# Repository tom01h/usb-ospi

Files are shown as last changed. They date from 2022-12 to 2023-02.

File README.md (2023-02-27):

# PCとFPGAをUSB接続する

## 概要
以下の接続でPCとFPGA間の高速転送をしたいプロジェクト。  
今はRead120Mbps,Write100Mbpsくらい。  
LinuxPC ←(USB-HS)→ USB3300 ←(ULPI)→ STM32H7B0 ←(OCTO SPI)→ FPGA

FPGA内ではAXIマスターポートをつける予定だけど、まだSPIクロックで動くBRAMにアクセスできるだけ。

USB転送はPCでは[libusb](https://github.com/libusb/libusb)、STM32では[tinyusb](https://github.com/hathach/tinyusb)を使ってVendorSpecificなバルク転送をします。  
OCTO SPIはSTM32はHALを使って、FPGAは適当に作ったRTLを使います。

## 部品
- PCはLinuxPCならたぶん何でもよい
- 基板を1枚こしらえました（[スケマ](https://github.com/tom01h/usb-ospi/blob/master/PCB/QMTECH/ospi.pdf)）
    - この基板の動作確認は200Tのみ
    - [8ピンのデータ用type-Cコネクタ](https://ja.aliexpress.com/item/1005004277420642.html)
    - [6ピンの電源用type-Cコネクタ](https://ja.aliexpress.com/item/1005004384274891.html)
    - USB3300-EZK
    - 24MHz 3225 のパッシブクォーツ水晶発振器 (2と4がグランド)
    - 1206 の抵抗とかコンデンサ
    - コネクタは次の組み合わせでぎりぎり干渉しない
        - STM32をとめる[コネクタ](https://ja.aliexpress.com/item/32892386779.html)
        - FPGAをとめる[コネクタオス](https://ja.aliexpress.com/item/1005004843759392.html)
            - これの11.2を、ピンが基板からはみ出ないところまでプラスチックをずらして使用
            - メスは普通のやつ
    - 他…
- QMTECHのFPGA (どっちか1個)
    - [200T](https://ja.aliexpress.com/item/1005002960622091.html)
    - [100T](https://ja.aliexpress.com/item/4000170003461.html)
- STM32H7
    - [WeActStudioのボード](https://ja.aliexpress.com/item/1005004466900940.html)
## 使い方
### ホスト
```
cd host/
cmake .
make
sudo ./main
```
### ファームウェア
- `firm/tinyusb`の下にtinyusbをクローンする
    - このリポジトリにあるファイルで上書きする
- usb_octospi.iocからプロジェクトを作る
    - このリポジトリにあるファイルで上書きする
- [ここ](https://github.com/hathach/tinyusb/discussions/633)に従って参照パスを追加する
```
- Right click the project, go to properties. in C/C++ General -> Paths and Symbols, in the "Includes" tab add a path, make it a workspace path, point it to the tinyusb/src directory. Then, in the "Source Location" tab, add folder, and also point it to tinyusb/src
- Add a tusb_config.h to your "Core/Inc"
```
### FPGA
- [なひビバ](https://github.com/tokuden/NahiViva)で次のどちらかのプロジェクトを再生してビルドする
    - QMT100/
    - QMT200/

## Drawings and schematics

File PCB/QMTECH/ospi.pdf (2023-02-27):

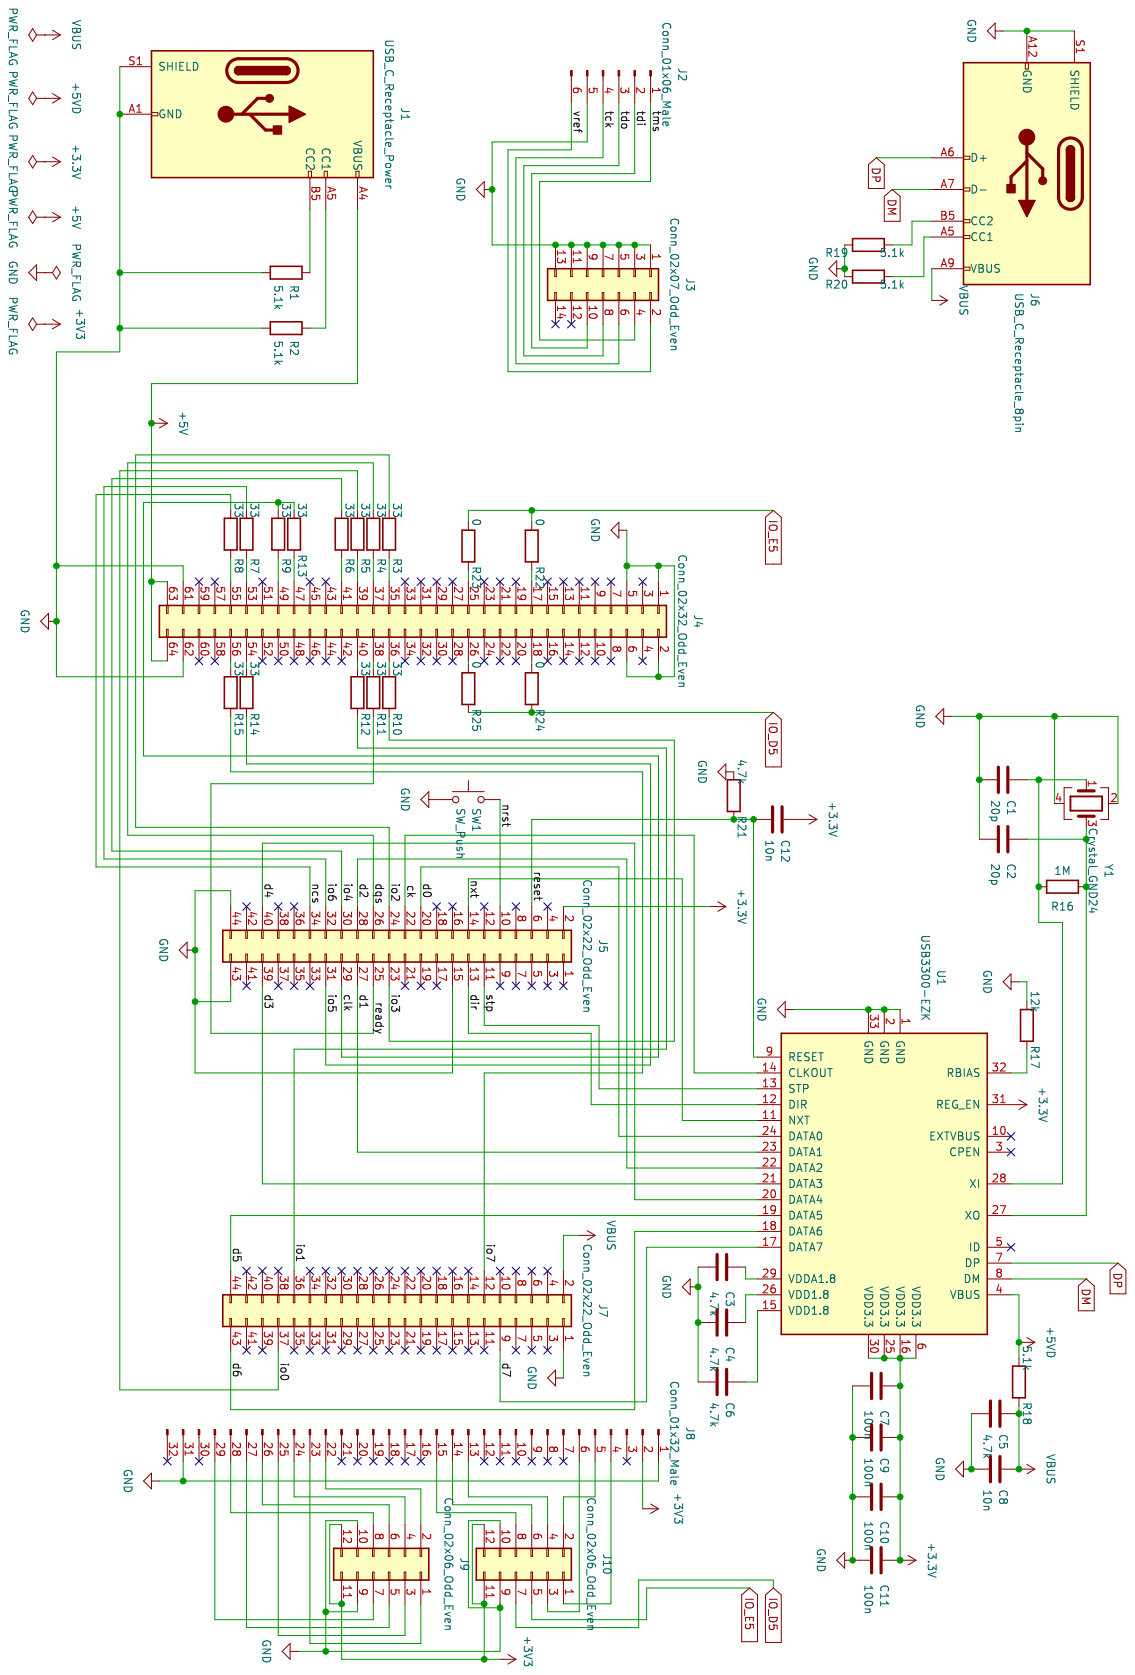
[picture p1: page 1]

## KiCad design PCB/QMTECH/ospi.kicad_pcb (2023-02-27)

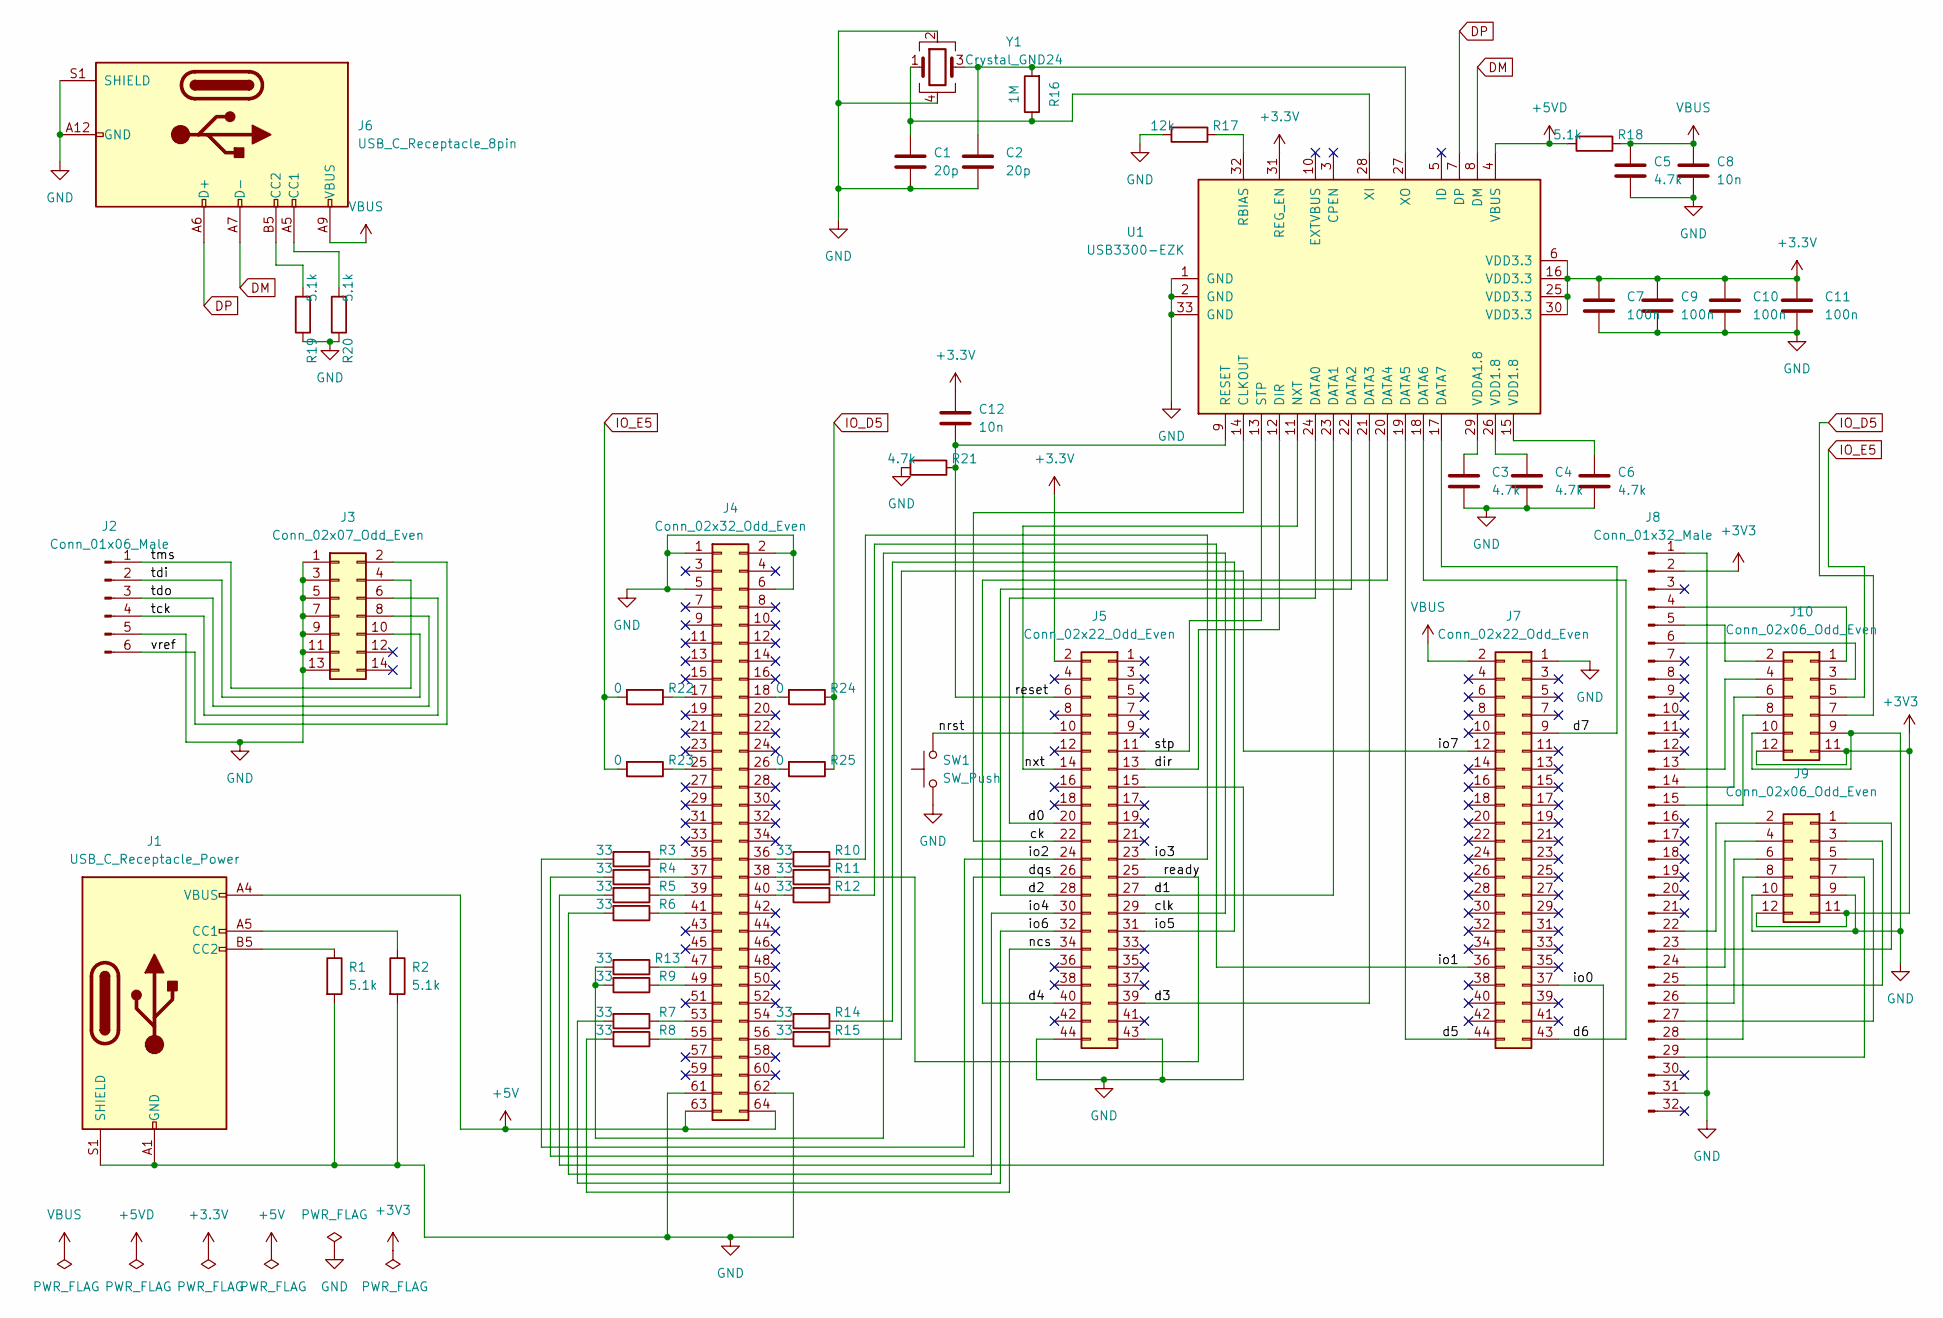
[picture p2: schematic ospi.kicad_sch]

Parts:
C1, C2: 20p; C_1206_3216Metric_Pad1.33x1.80mm_HandSolder
C3, C4, C5, C6: 4.7k; C_1206_3216Metric_Pad1.33x1.80mm_HandSolder
C7, C9, C10, C11: 100n; C_1206_3216Metric_Pad1.33x1.80mm_HandSolder
C8, C12: 10n; C_1206_3216Metric_Pad1.33x1.80mm_HandSolder
J1: USB_C_Receptacle_Power
J2: Conn_01x06_Male; PinSocket_1x06_P2.54mm_Vertical
J3: Conn_02x07_Odd_Even; PinHeader_2x07_P2.00mm_Vertical
J4: Conn_02x32_Odd_Even; PinSocket_2x32_P2.54mm_Vertical
J5, J7: Conn_02x22_Odd_Even; PinSocket_2x22_P2.54mm_Vertical
J6: USB_C_Receptacle_8pin
J8: Conn_01x32_Male; PinSocket_1x32_P2.54mm_Vertical
J9, J10: Conn_02x06_Odd_Even; PinSocket_2x06_P2.54mm_Vertical
R1, R2, R18, R19, R20: 5.1k; R_1206_3216Metric_Pad1.30x1.75mm_HandSolder
R3, R4, R5, R6, R7, R8, R9, R10, R11, R12, R13, R14, R15: 33; R_1206_3216Metric_Pad1.30x1.75mm_HandSolder
R16: 1M; R_1206_3216Metric_Pad1.30x1.75mm_HandSolder
R17: 12k; R_1206_3216Metric_Pad1.30x1.75mm_HandSolder
R21: 4.7k; R_1206_3216Metric_Pad1.30x1.75mm_HandSolder
R22, R23, R24, R25: 0; R_1206_3216Metric_Pad1.30x1.75mm_HandSolder
SW1: SW_Push; SW_SPST_CK_RS282G05A3
U1: USB3300-EZK; QFN-32-1EP_5x5mm_P0.5mm_EP3.45x3.45mm_ThermalVias
Y1: Crystal_GND24; Crystal_SMD_3225-4Pin_3.2x2.5mm_HandSoldering

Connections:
+3.3V: C7.1, C9.1, C10.1, C11.1, C12.1, J5.2, U1.6 (VDD3.3), U1.16 (VDD3.3), U1.25 (VDD3.3), U1.30 (VDD3.3), U1.31 (REG_EN)
+3V3: J8.2, J9.11, J9.12, J10.11, J10.12
+5V: J1.A4 (VBUS), J1.A9 (VBUS), J1.B4 (VBUS), J1.B9 (VBUS), J4.63, J4.64
+5VD: R18.2, U1.4 (VBUS)
/ck: J5.22, U1.14 (CLKOUT)
/clk: J5.29, R9.2, R13.2
/d0: J5.20, U1.24 (DATA0)
/d1: J5.27, U1.23 (DATA1)
/d2: J5.28, U1.22 (DATA2)
/d3: J5.39, U1.21 (DATA3)
/d4: J5.40, U1.20 (DATA4)
/d5: J7.44, U1.19 (DATA5)
/d6: J7.43, U1.18 (DATA6)
/d7: J7.9, U1.17 (DATA7)
/dir: J5.13, U1.12 (DIR)
/dqs: J5.26, R4.2
/io0: J7.37, R5.2
/io1: J7.36, R12.1
/io2: J5.24, R3.2
/io3: J5.23, R10.1
/io4: J5.30, R6.2
/io5: J5.31, R14.1
/io6: J5.32, R7.2
/io7: J7.12, R15.1
/ncs: J5.34, R8.2
/nrst: J5.10, SW1.2
/nxt: J5.14, U1.11 (NXT)
/ready: J5.25, R11.1
/reset: C12.2, J5.6, R21.1, U1.9 (RESET)
/stp: J5.11, U1.13 (STP)
/tck: J2.4, J3.6
/tdi: J2.2, J3.10
/tdo: J2.3, J3.8
/tms: J2.1, J3.4
/vref: J2.6, J3.2
DM: J6.A7 (D-), U1.8 (DM)
DP: J6.A6 (D+), U1.7 (DP)
GND: C1.2, C2.2, C3.2, C4.2, C5.2, C6.2, C7.2, C8.2, C9.2, C10.2, C11.2, J1.A1 (GND), J1.A12 (GND), J1.B1 (GND), J1.B12 (GND), J1.S1 (SHIELD), J2.5, J3.1, J3.3, J3.5, J3.7, J3.9, J3.11, J3.13, J4.1, J4.2, J4.5, J4.6, J4.61, J4.62, J5.15, J5.43, J5.44, J6.A12 (GND), J6.B12 (GND), J6.S1 (SHIELD), J7.1, J8.1, J8.31, J9.9, J9.10, J10.9, J10.10, R1.2, R2.2, R17.2, R19.1, R20.1, R21.2, SW1.1, U1.1 (GND), U1.2 (GND), U1.33 (GND), Y1.2, Y1.4
IO_D5: J10.7, R24.1, R25.1
IO_E5: J10.5, R22.2, R23.2
unnamed: C1.1, R16.1, U1.28 (XI), Y1.1
unnamed: C2.1, R16.2, U1.27 (XO), Y1.3
unnamed: C3.1, U1.29 (VDDA1.8)
unnamed: C4.1, U1.26 (VDD1.8)
unnamed: C6.1, U1.15 (VDD1.8)
unnamed: J1.A5 (CC1), R2.1
unnamed: J1.B5 (CC2), R1.1
unnamed: J4.17, R22.1
unnamed: J4.18, R24.2
unnamed: J4.25, R23.1
unnamed: J4.26, R25.2
unnamed: J4.35, R3.1
unnamed: J4.36, R10.2
unnamed: J4.37, R4.1
unnamed: J4.38, R11.2
unnamed: J4.39, R5.1
unnamed: J4.40, R12.2
unnamed: J4.41, R6.1
unnamed: J4.47, R13.1
unnamed: J4.49, R9.1
unnamed: J4.53, R7.1
unnamed: J4.54, R14.2
unnamed: J4.55, R8.1
unnamed: J4.56, R15.2
unnamed: J6.A5 (CC1), R20.2
unnamed: J6.B5 (CC2), R19.2
unnamed: J8.22, J9.2
unnamed: J8.23, J9.1
unnamed: J8.24, J9.4
unnamed: J8.25, J9.3
unnamed: J8.26, J9.6
unnamed: J8.27, J9.5
unnamed: J8.28, J9.8
unnamed: J8.29, J9.7
unnamed: J8.4, J10.1
unnamed: J8.5, J10.2
unnamed: J8.6, J10.3
unnamed: J8.13, J10.4
unnamed: J8.14, J10.6
unnamed: J8.15, J10.8
unnamed: R17.1, U1.32 (RBIAS)
VBUS: C5.1, C8.1, J6.A9 (VBUS), J6.B9 (VBUS), J7.2, R18.1

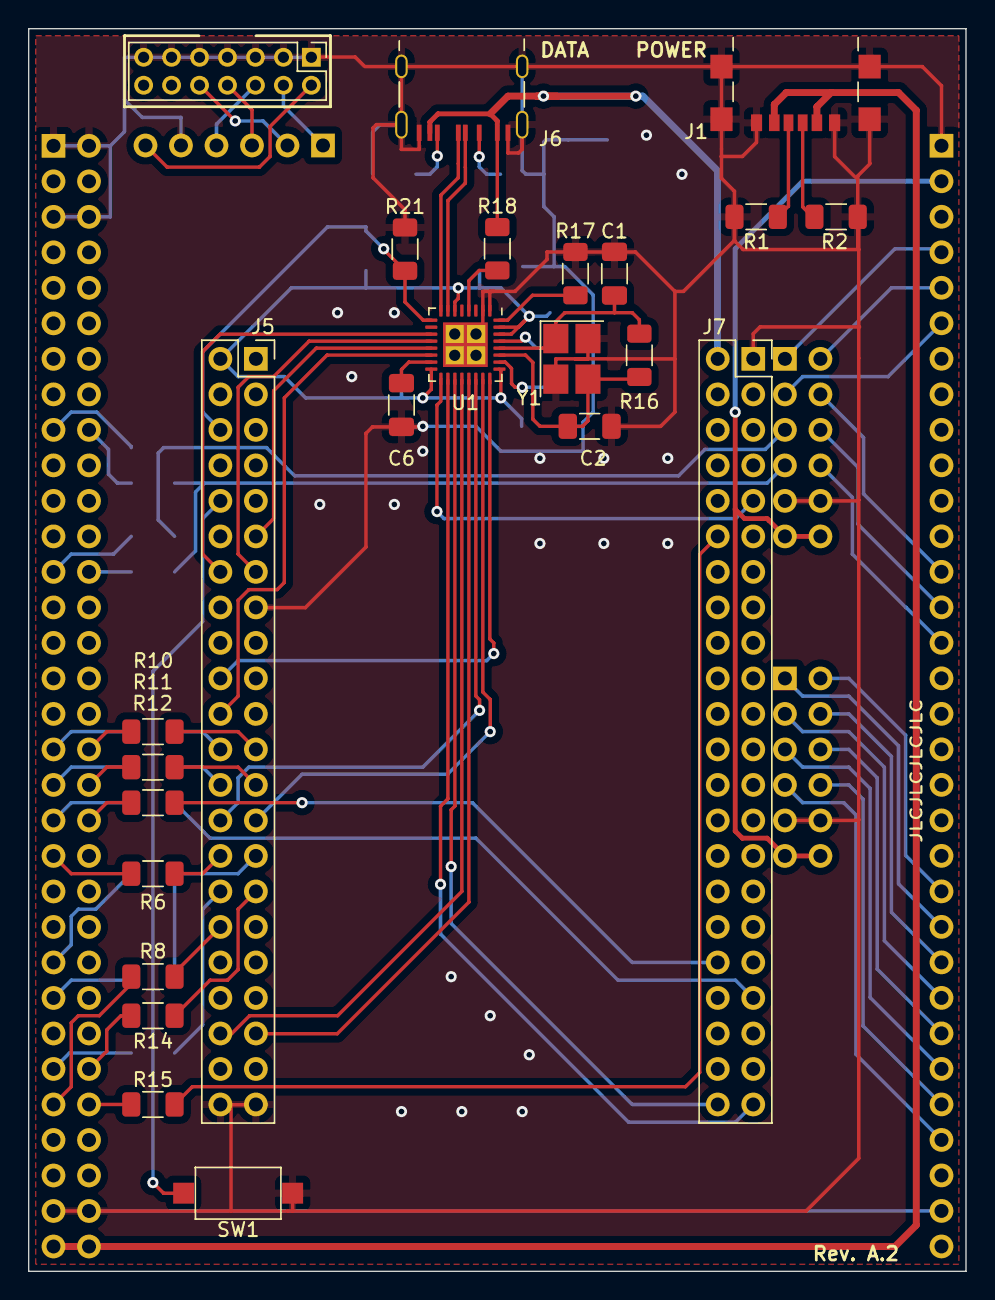
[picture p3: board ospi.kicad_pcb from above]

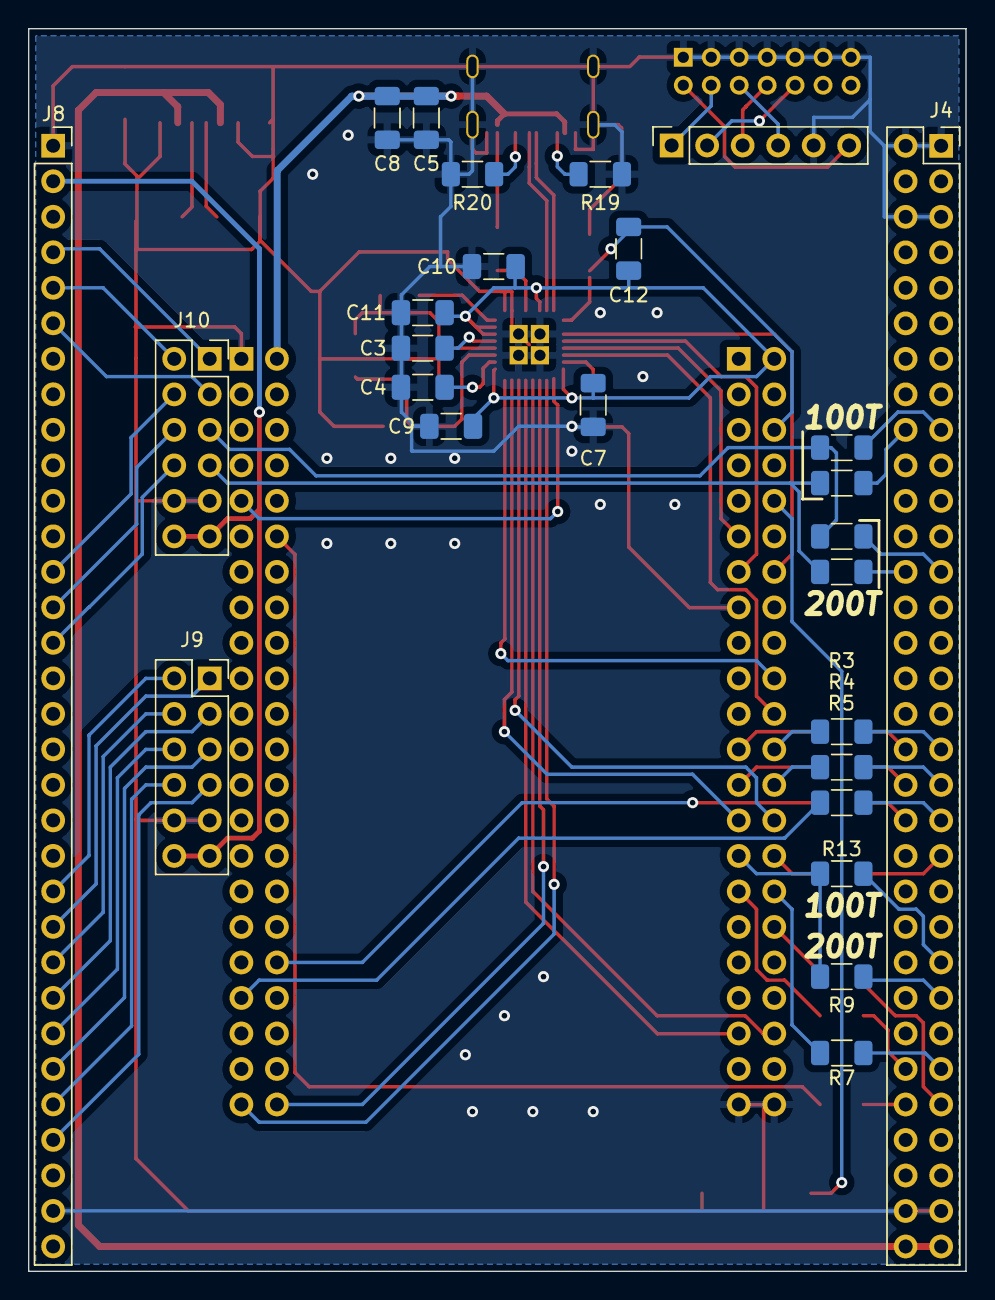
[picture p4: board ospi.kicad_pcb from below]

Board: 2 copper layers, 67.1 x 88.9 mm, 50 parts (26 on the bottom side), 82 nets.

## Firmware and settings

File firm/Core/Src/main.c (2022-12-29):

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
/* Includes ------------------------------------------------------------------*/
#include "main.h"

/* USER CODE BEGIN Includes */
#include "tusb.h"

/* USER CODE END Includes */


OSPI_HandleTypeDef hospi1;
MDMA_HandleTypeDef hmdma_octospi1_fifo_th;

PCD_HandleTypeDef hpcd_USB_OTG_HS;

/* USER CODE BEGIN PV */
buffer_info buffer_info_axm;

/* USER CODE END PV */

void SystemClock_Config(void);
static void MX_GPIO_Init(void);
static void MX_MDMA_Init(void);
static void MX_OCTOSPI1_Init(void);
static void MX_USB_OTG_HS_PCD_Init(void);
/* USER CODE BEGIN 0 */

void from_host_task(OSPI_RegularCmdTypeDef *sCommand)
{
	if ((buffer_info_axm.busy == false)) {
		buffer_info_axm.busy = true;
		uint com_size = 0;
		if (tud_vendor_available()) {
			com_size = tud_vendor_read(buffer_info_axm.buffer[0], 512);
			//tud_vendor_read_flush();
		}else{
			tud_task();
		}
		if (com_size != 0) {
			sCommand->Instruction = *(uint32_t *)&buffer_info_axm.buffer[0][0];
			buffer_info_axm.count = (sCommand->Instruction & 0x00ffffff)+1;

			sCommand->Address     = *(uint32_t *)&buffer_info_axm.buffer[0][4];

			uint count = buffer_info_axm.count;

			if((buffer_info_axm.buffer[0][3]&0xf0)==(LINEAR_BURST_WRITE<<4)) {     // LINEAR_BURST_WRITE
				sCommand->DummyCycles = DUMMY_CLOCK_CYCLES_SRAM_WRITE;
				int wp = 0;
				int rp = 0;
				while(tud_vendor_read(buffer_info_axm.buffer[wp], 512) == 0){tud_task();}
				do{
					if(count > 256){
						sCommand->NbData  = 256;
						count -= 256;
						sCommand->Instruction &= 0xff0000ff;/////////////|0xff
					} else {
						sCommand->NbData  = count;
						count = 0;
						sCommand->Instruction &= 0xff0000ff;
					}
					SCB_CleanDCache_by_Addr((uint32_t*)buffer_info_axm.buffer[rp], 512);

					if (HAL_OSPI_Command(&hospi1, sCommand, HAL_OSPI_TIMEOUT_DEFAULT_VALUE) != HAL_OK) {Error_Handler();}
					if (HAL_OSPI_Transmit_DMA(&hospi1, buffer_info_axm.buffer[rp])!= HAL_OK)           {Error_Handler();}
					while(HAL_OSPI_GetState(&hospi1) == HAL_OSPI_STATE_BUSY_TX){}
					sCommand->Address += 256;

					if(count > 0){
						if(count > 256){
							sCommand->NbData  = 256;
							count -= 256;
							sCommand->Instruction &= 0xff0000ff;/////////////|0xff
						} else {
							sCommand->NbData  = count;
							count = 0;
							sCommand->Instruction &= 0xff0000ff;
						}

						if (HAL_OSPI_Command(&hospi1, sCommand, HAL_OSPI_TIMEOUT_DEFAULT_VALUE) != HAL_OK) {Error_Handler();}
						if (HAL_OSPI_Transmit_DMA(&hospi1, &buffer_info_axm.buffer[rp][256])!= HAL_OK)     {Error_Handler();}
						if(count > 0) {
							wp = (wp +1) %2;
							while(tud_vendor_read(buffer_info_axm.buffer[wp], 512) == 0){tud_task();}
						}
						while(HAL_OSPI_GetState(&hospi1) == HAL_OSPI_STATE_BUSY_TX){}
						sCommand->Address += 256;
					}
					rp = (rp +1) %2;
				} while(count > 0);
			} else {                                                             // LINEAR_BURST_READ
				sCommand->DummyCycles = DUMMY_CLOCK_CYCLES_SRAM_READ;
				int wp = 0;
				int rp = 0;
				do{
					SCB_InvalidateDCache_by_Addr((uint32_t*)buffer_info_axm.buffer[wp], 512);

					if(count > 256){
						sCommand->NbData  = 256;
						count -= 256;
						sCommand->Instruction &= 0xff0000ff;/////////////|0xff
					} else {
						sCommand->NbData  = count;
						count = 0;
						sCommand->Instruction &= 0xff0000ff;
					}

					if (HAL_OSPI_Command(&hospi1, sCommand, HAL_OSPI_TIMEOUT_DEFAULT_VALUE) != HAL_OK) {Error_Handler();}
					if (HAL_OSPI_Receive_DMA(&hospi1, buffer_info_axm.buffer[wp])!= HAL_OK)            {Error_Handler();}
					if(rp != wp) {
						while(tud_vendor_write(buffer_info_axm.buffer[rp], 512) == 0){tud_task();}///////////////////////////////512
						rp = (rp +1) %2;
					}
					while(HAL_OSPI_GetState(&hospi1) == HAL_OSPI_STATE_BUSY_RX){}
					sCommand->Address += 256;

					if(count > 0){
						if(count > 256){
							sCommand->NbData  = 256;
							count -= 256;
							sCommand->Instruction &= 0xff0000ff;/////////////|0xff
						} else {
							sCommand->NbData  = count;
							count = 0;
							sCommand->Instruction &= 0xff0000ff;
						}

						if (HAL_OSPI_Command(&hospi1, sCommand, HAL_OSPI_TIMEOUT_DEFAULT_VALUE) != HAL_OK) {Error_Handler();}
						if (HAL_OSPI_Receive_DMA(&hospi1, &buffer_info_axm.buffer[wp][256])!= HAL_OK)      {Error_Handler();}
						while(HAL_OSPI_GetState(&hospi1) == HAL_OSPI_STATE_BUSY_RX){}
						sCommand->Address += 256;
					}

					wp = (wp +1) %2;
					tud_vendor_flush();
				} while(count > 0);
				while(tud_vendor_write(buffer_info_axm.buffer[rp], 512) == 0){tud_task();}///////////////////////////////512
			}
		}
		buffer_info_axm.busy = false;
	}
}

/* USER CODE END 0 */

/**
  * @brief  The application entry point.
  * @retval int
  */
int main(void)
{
  /* Enable I-Cache---------------------------------------------------------*/
  SCB_EnableICache();

  /* Enable D-Cache---------------------------------------------------------*/
  SCB_EnableDCache();

  /* MCU Configuration--------------------------------------------------------*/

  /* Reset of all peripherals, Initializes the Flash interface and the Systick. */
  HAL_Init();

  /* Configure the system clock */
  SystemClock_Config();

  /* Initialize all configured peripherals */
  MX_GPIO_Init();
  MX_MDMA_Init();
  MX_OCTOSPI1_Init();
  MX_USB_OTG_HS_PCD_Init();
  /* Infinite loop */
  /* USER CODE BEGIN WHILE */
  tusb_init();

  OSPI_RegularCmdTypeDef sCommand;
  sCommand.OperationType = HAL_OSPI_OPTYPE_COMMON_CFG;
  sCommand.FlashId = HAL_OSPI_FLASH_ID_1;
  sCommand.InstructionMode = HAL_OSPI_INSTRUCTION_8_LINES;
  sCommand.InstructionSize = HAL_OSPI_INSTRUCTION_32_BITS;
  sCommand.AddressMode = HAL_OSPI_ADDRESS_8_LINES;
  sCommand.AddressSize = HAL_OSPI_ADDRESS_32_BITS;
  sCommand.AlternateBytesMode = HAL_OSPI_ALTERNATE_BYTES_NONE;
  sCommand.DataMode = HAL_OSPI_DATA_8_LINES;
  sCommand.SIOOMode = HAL_OSPI_SIOO_INST_EVERY_CMD;
  sCommand.InstructionDtrMode = HAL_OSPI_INSTRUCTION_DTR_DISABLE;
  sCommand.AddressDtrMode = HAL_OSPI_ADDRESS_DTR_DISABLE;
  sCommand.DataDtrMode = HAL_OSPI_DATA_DTR_DISABLE;
  sCommand.DQSMode = HAL_OSPI_DQS_DISABLE;

  while (1)
  {
    /* USER CODE END WHILE */

    /* USER CODE BEGIN 3 */
      //HAL_Delay(1);
	  tud_task();
	  from_host_task(&sCommand);
  }
  /* USER CODE END 3 */
}

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


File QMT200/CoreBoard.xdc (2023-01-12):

#### SYSTEM
set_property IOSTANDARD LVCMOS33 [get_ports sys_clk]
set_property PACKAGE_PIN W19 [get_ports sys_clk]
set_property IOSTANDARD LVCMOS33 [get_ports sys_rst_n]
set_property PACKAGE_PIN Y6 [get_ports sys_rst_n]

set_property PACKAGE_PIN E3 [get_ports {ledout_0[1]}]
set_property PACKAGE_PIN F3 [get_ports {ledout_0[0]}]
set_property IOSTANDARD LVCMOS33 [get_ports {ledout_0[0]}]
set_property IOSTANDARD LVCMOS33 [get_ports {ledout_0[1]}]

set_property DRIVE 4 [get_ports {data_0[7]}]
set_property DRIVE 4 [get_ports {data_0[6]}]
set_property DRIVE 4 [get_ports {data_0[5]}]
set_property DRIVE 4 [get_ports {data_0[4]}]
set_property DRIVE 4 [get_ports {data_0[3]}]
set_property DRIVE 4 [get_ports {data_0[2]}]
set_property DRIVE 4 [get_ports {data_0[1]}]
set_property DRIVE 4 [get_ports {data_0[0]}]
set_property SLEW FAST [get_ports {data_0[7]}]
set_property SLEW FAST [get_ports {data_0[6]}]
set_property SLEW FAST [get_ports {data_0[5]}]
set_property SLEW FAST [get_ports {data_0[4]}]
set_property SLEW FAST [get_ports {data_0[3]}]
set_property SLEW FAST [get_ports {data_0[2]}]
set_property SLEW FAST [get_ports {data_0[1]}]
set_property SLEW FAST [get_ports {data_0[0]}]
set_property IOSTANDARD LVCMOS33 [get_ports {data_0[7]}]
set_property IOSTANDARD LVCMOS33 [get_ports {data_0[6]}]
set_property IOSTANDARD LVCMOS33 [get_ports {data_0[5]}]
set_property IOSTANDARD LVCMOS33 [get_ports {data_0[4]}]
set_property IOSTANDARD LVCMOS33 [get_ports {data_0[3]}]
set_property IOSTANDARD LVCMOS33 [get_ports {data_0[2]}]
set_property IOSTANDARD LVCMOS33 [get_ports {data_0[1]}]
set_property IOSTANDARD LVCMOS33 [get_ports {data_0[0]}]
set_property PACKAGE_PIN V4 [get_ports clkin_0]
set_property IOSTANDARD LVCMOS33 [get_ports clkin_0]
set_property PACKAGE_PIN AB5 [get_ports {data_0[7]}]
set_property PACKAGE_PIN Y4 [get_ports {data_0[6]}]
set_property PACKAGE_PIN AA4 [get_ports {data_0[5]}]
set_property PACKAGE_PIN T1 [get_ports {data_0[4]}]
set_property PACKAGE_PIN P4 [get_ports {data_0[3]}]
set_property PACKAGE_PIN P5 [get_ports {data_0[2]}]
set_property PACKAGE_PIN U5 [get_ports {data_0[1]}]
set_property PACKAGE_PIN T5 [get_ports {data_0[0]}]
set_property IOSTANDARD LVCMOS33 [get_ports dqs_0]
set_property IOSTANDARD LVCMOS33 [get_ports ncs_0]
set_property DRIVE 8 [get_ports dqs_0]
set_property SLEW FAST [get_ports dqs_0]
set_property PACKAGE_PIN R4 [get_ports dqs_0]
set_property PACKAGE_PIN AA5 [get_ports ncs_0]


create_clock -period 16.667 -name spi_clk [get_ports clkin_0]

set_output_delay -clock spi_clk 10.000 [get_ports {data_0[7]}]
set_output_delay -clock spi_clk 10.000 [get_ports {data_0[6]}]
set_output_delay -clock spi_clk 10.000 [get_ports {data_0[5]}]
set_output_delay -clock spi_clk 10.000 [get_ports {data_0[4]}]
set_output_delay -clock spi_clk 10.000 [get_ports {data_0[3]}]
set_output_delay -clock spi_clk 10.000 [get_ports {data_0[2]}]
set_output_delay -clock spi_clk 10.000 [get_ports {data_0[1]}]
set_output_delay -clock spi_clk 10.000 [get_ports {data_0[0]}]

set_input_delay -clock spi_clk 10.000 [get_ports {data_0[7]}]
set_input_delay -clock spi_clk 10.000 [get_ports {data_0[6]}]
set_input_delay -clock spi_clk 10.000 [get_ports {data_0[5]}]
set_input_delay -clock spi_clk 10.000 [get_ports {data_0[4]}]
set_input_delay -clock spi_clk 10.000 [get_ports {data_0[3]}]
set_input_delay -clock spi_clk 10.000 [get_ports {data_0[2]}]
set_input_delay -clock spi_clk 10.000 [get_ports {data_0[1]}]
set_input_delay -clock spi_clk 10.000 [get_ports {data_0[0]}]

set_input_delay -clock spi_clk 10.000 [get_ports ncs_0]
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

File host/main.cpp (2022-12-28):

#include <stdio.h>
#include <sys/time.h>

#include <unistd.h>
#include <stdlib.h>

//#define BUFFERSIZE 256*4
#define BUFFERSIZE 512*512
#define TRANSFERSIZE 256
//#define BUFFERSIZE 64

#include <libusb.h>
#define PMODUSB_VID       0x0483
#define PMODUSB_PID       0x5741
#define PMODUSB_INTF      2
#define PMODUSB_READ_EP   0x84
#define PMODUSB_WRITE_EP  0x03
libusb_context *usb_ctx;
libusb_device_handle *dev_handle;

int device_init()
{
    int ret;

    if (libusb_init(&usb_ctx) < 0) {
        printf("[ERROR] libusb init failed!\n");
        return -1;
    }
    dev_handle = libusb_open_device_with_vid_pid(usb_ctx, PMODUSB_VID, PMODUSB_PID);
    if (!dev_handle) {
        printf("[ERROR] failed to open usb device!\n");
        libusb_exit(usb_ctx);
        return -1;
    }
    ret = libusb_claim_interface(dev_handle, PMODUSB_INTF);
    if (ret) {
        printf("[!] libusb error while claiming PMODUSB interface\n");
        libusb_close(dev_handle);
        libusb_exit(usb_ctx);
        return -1;
    }

    return 0; // success
}

void device_close()
{
    if (dev_handle)
        libusb_close(dev_handle);
    if (usb_ctx)
        libusb_exit(usb_ctx);
}

int read_dev(int size, u_int8_t *com_data, u_int8_t *receive_data) {
    int r;
    int actual_length = 0;

    // read command 送信
    r = libusb_bulk_transfer(dev_handle, PMODUSB_WRITE_EP, com_data, 8 , &actual_length, 1000);
    if ( r != 0 ){
        printf("write_dev error %d\n", r);
        device_close();
        return -1;
    }
    // read data 受信
    r = libusb_bulk_transfer(dev_handle, PMODUSB_READ_EP, receive_data, size, &actual_length, 1000);
    if (r < 0) {
        printf("read_dev error %d\n", r);
        device_close();
        return -1;
    }

    return actual_length;
}

int write_dev(int size, u_int8_t *com_data, u_int8_t *send_data) {
    int r;
    int actual_length = 0;

    // write command 送信
    r = libusb_bulk_transfer(dev_handle, PMODUSB_WRITE_EP, com_data, 8 , &actual_length, 1000);
    if ( r != 0 ){
        printf("write_dev error %d\n", r);
        device_close();
        return -1;
    }
    // data 送信
    r = libusb_bulk_transfer(dev_handle, PMODUSB_WRITE_EP, send_data, size , &actual_length, 1000);
    if ( r != 0 ){
        printf("write_dev error %d\n", r);
        device_close();
        return -1;
    }

    return actual_length;
}

int main(){
    unsigned int sec;
    int nsec;
    double rw_sec;
    double r_sec;
    struct timespec start_time, end_time;

    u_int8_t aComBuffer[8];            // command[4]+address[4]
    u_int8_t aTxBuffer[BUFFERSIZE];    // data[BUFFERSIZE]
    u_int8_t aRxBuffer[BUFFERSIZE];    // data[BUFFERSIZE]

    int microsecond = 1 * 1000 * 1000;

    // Init
    if (device_init() != 0) {
        return -1;
    }

    while(1){
        for(int i = 0; i < BUFFERSIZE; i++){
            aTxBuffer[i]    = rand();
        }

        clock_gettime(CLOCK_REALTIME, &start_time);

        uint32_t address = 0;

        int actual_length = 0;

        address = 0;//0x12345678;

        actual_length = 0;

        aComBuffer[0] =  (BUFFERSIZE-1)         %0x100;
        aComBuffer[1] = ((BUFFERSIZE-1)/0x100)  %0x100;
        aComBuffer[2] = ((BUFFERSIZE-1)/0x10000);
        aComBuffer[3] = 0xA0+4;
        aComBuffer[4] =  address           %0x100;
        aComBuffer[5] = (address/0x100)    %0x100;
        aComBuffer[6] = (address/0x10000)  %0x100;
        aComBuffer[7] = (address/0x1000000);
        actual_length = write_dev(BUFFERSIZE, aComBuffer, aTxBuffer);
        
        if(actual_length < 0){
            printf("write error\n");
            return -1;
        }



        address = 0;//0x12345678;

        actual_length = 0;
        aComBuffer[0] =  (BUFFERSIZE-1)         %0x100;
        aComBuffer[1] = ((BUFFERSIZE-1)/0x100)  %0x100;
        aComBuffer[2] = ((BUFFERSIZE-1)/0x10000);
        aComBuffer[3] = 0x20+4;
        aComBuffer[4] =  address           %0x100;
        aComBuffer[5] = (address/0x100)    %0x100;
        aComBuffer[6] = (address/0x10000)  %0x100;
        aComBuffer[7] = (address/0x1000000);
        actual_length = read_dev(BUFFERSIZE, aComBuffer, aRxBuffer);
        if(actual_length < 0){
            printf("read error\n");    
            return -1;
        }
        
        clock_gettime(CLOCK_REALTIME, &end_time);
        sec = end_time.tv_sec - start_time.tv_sec;
        nsec = end_time.tv_nsec - start_time.tv_nsec;
        rw_sec = (double)sec + (double)nsec / (1000 * 1000 * 1000);
        printf("R/W time:%f, %f Mpbs\n", rw_sec, BUFFERSIZE*8*2*1/rw_sec/1000/1000);

        for(int i = 0; i < BUFFERSIZE/16; i++){
            for(int j = 0; j < 16; j++){
                if(aTxBuffer[i*16+j] != aRxBuffer[i*16+j]){
                    printf("Error %i, %02x, %02x ", i*16+j, aTxBuffer[i*16+j], aRxBuffer[i*16+j]);
                } else {
                    //printf("%02x ",aTxBuffer[i*16+j]);
                }
            }
            //printf("\n");
        }
        //printf("\n");
      
        /////////////// READ /////////////////
        
        address = 0;//0x12345678;
        
        clock_gettime(CLOCK_REALTIME, &start_time);

        actual_length = 0;
        aComBuffer[0] =  (BUFFERSIZE-1)         %0x100;
        aComBuffer[1] = ((BUFFERSIZE-1)/0x100)  %0x100;
        aComBuffer[2] = ((BUFFERSIZE-1)/0x10000);
        aComBuffer[3] = 0x20+4;
        aComBuffer[4] =  address           %0x100;
        aComBuffer[5] = (address/0x100)    %0x100;
        aComBuffer[6] = (address/0x10000)  %0x100;
        aComBuffer[7] = (address/0x1000000);
        actual_length = read_dev(BUFFERSIZE, aComBuffer, aRxBuffer);
        if(actual_length < 0){
            printf("read error\n");    
            return -1;
        }
        
        clock_gettime(CLOCK_REALTIME, &end_time);
        sec = end_time.tv_sec - start_time.tv_sec;
        nsec = end_time.tv_nsec - start_time.tv_nsec;
        r_sec = (double)sec + (double)nsec / (1000 * 1000 * 1000);
        printf("R time:%f, %f Mpbs\n", r_sec, BUFFERSIZE*8/r_sec/1000/1000);
        printf("W time:%f, %f Mpbs\n", rw_sec-r_sec, BUFFERSIZE*8/(rw_sec-r_sec)/1000/1000);

        for(int i = 0; i < BUFFERSIZE/16; i++){
            for(int j = 0; j < 16; j++){
                if(aTxBuffer[i*16+j] != aRxBuffer[i*16+j]){
                    printf("Error %i, %02x, %02x ", i*16+j, aTxBuffer[i*16+j], aRxBuffer[i*16+j]);
                } else {
                    //printf("%02x ",aTxBuffer[i*16+j]);
                }
            }
            //printf("\n");
        }
        printf("\n");

        usleep(microsecond);

    }
    return 0;
}

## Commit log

2022-12-06 合成 QMT 100T
2022-12-24 プロトコル WIP
    libusbの分割未対応
2022-12-26 プロトコル READのみ分割対応
    libusbは分割なし
    USBは512B
    OCTOSPIは256B (毎回新規コマンド)
2022-12-28 プロトコル分割 R/Wともに対応
2022-12-28 ダブルバッファ
2022-12-29 OCTO SPI 30->60MHz
2023-01-12 200T追加 クロックピン変更
2023-01-12 不要ファイル削除
2023-01-15 add PCB
    [ospi.kicad_pcb, ospi.kicad_sch]
2023-02-27 PCB更新
    [ospi.kicad_pcb, ospi.kicad_sch]

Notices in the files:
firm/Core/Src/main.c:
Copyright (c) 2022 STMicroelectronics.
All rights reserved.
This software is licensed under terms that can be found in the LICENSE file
